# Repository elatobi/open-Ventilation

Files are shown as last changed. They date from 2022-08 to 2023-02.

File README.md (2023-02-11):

# Open-Ventilation



This is an Arduino sketch to PWM controll a 12V Fan, the PCB files for the PCB and the CAD-Data for my Printercabinet housing. 

The mainscreen shows the current temperature, material and the dutycicle of the fan.



By pressing the button of the rotaryencoder for 3s, the setup menu gets opend. Ther you can set the different materials.
For now there is PLA, PETG, FLEX, PC and IGLIDUR a material from Igus. 
Each material has its own min and max temp. Between thise temperatures the fan runns with a maped dutycicle, below the min temp the fan is not running.
Abov the max temp the fan runns with 100% dutycicle.



In the PCB folder are the files for getting the PCB according to the circuit diagram.





You can finde the CAD-Files for the Housing at my Printables Profile https://www.printables.com/de/model/162908-housing-for-cabinet-ventilation-control

# BOM

1 x Arduino Nano\
1 x 16x2 LCD with i2C backpack\
1 x DS18B2\
1 x Rotaryencoder with button\
1 x IRFZ44N MOSFET\
1 x 1N4007 Diode\
1 x 10 kΩ Resistor\
1 x 4,7 kΩ Resistor\
1 x 220 Ω Resistor\
1 x 12V Fan (2 or 3 Wire)\
1 x 12V powersuply

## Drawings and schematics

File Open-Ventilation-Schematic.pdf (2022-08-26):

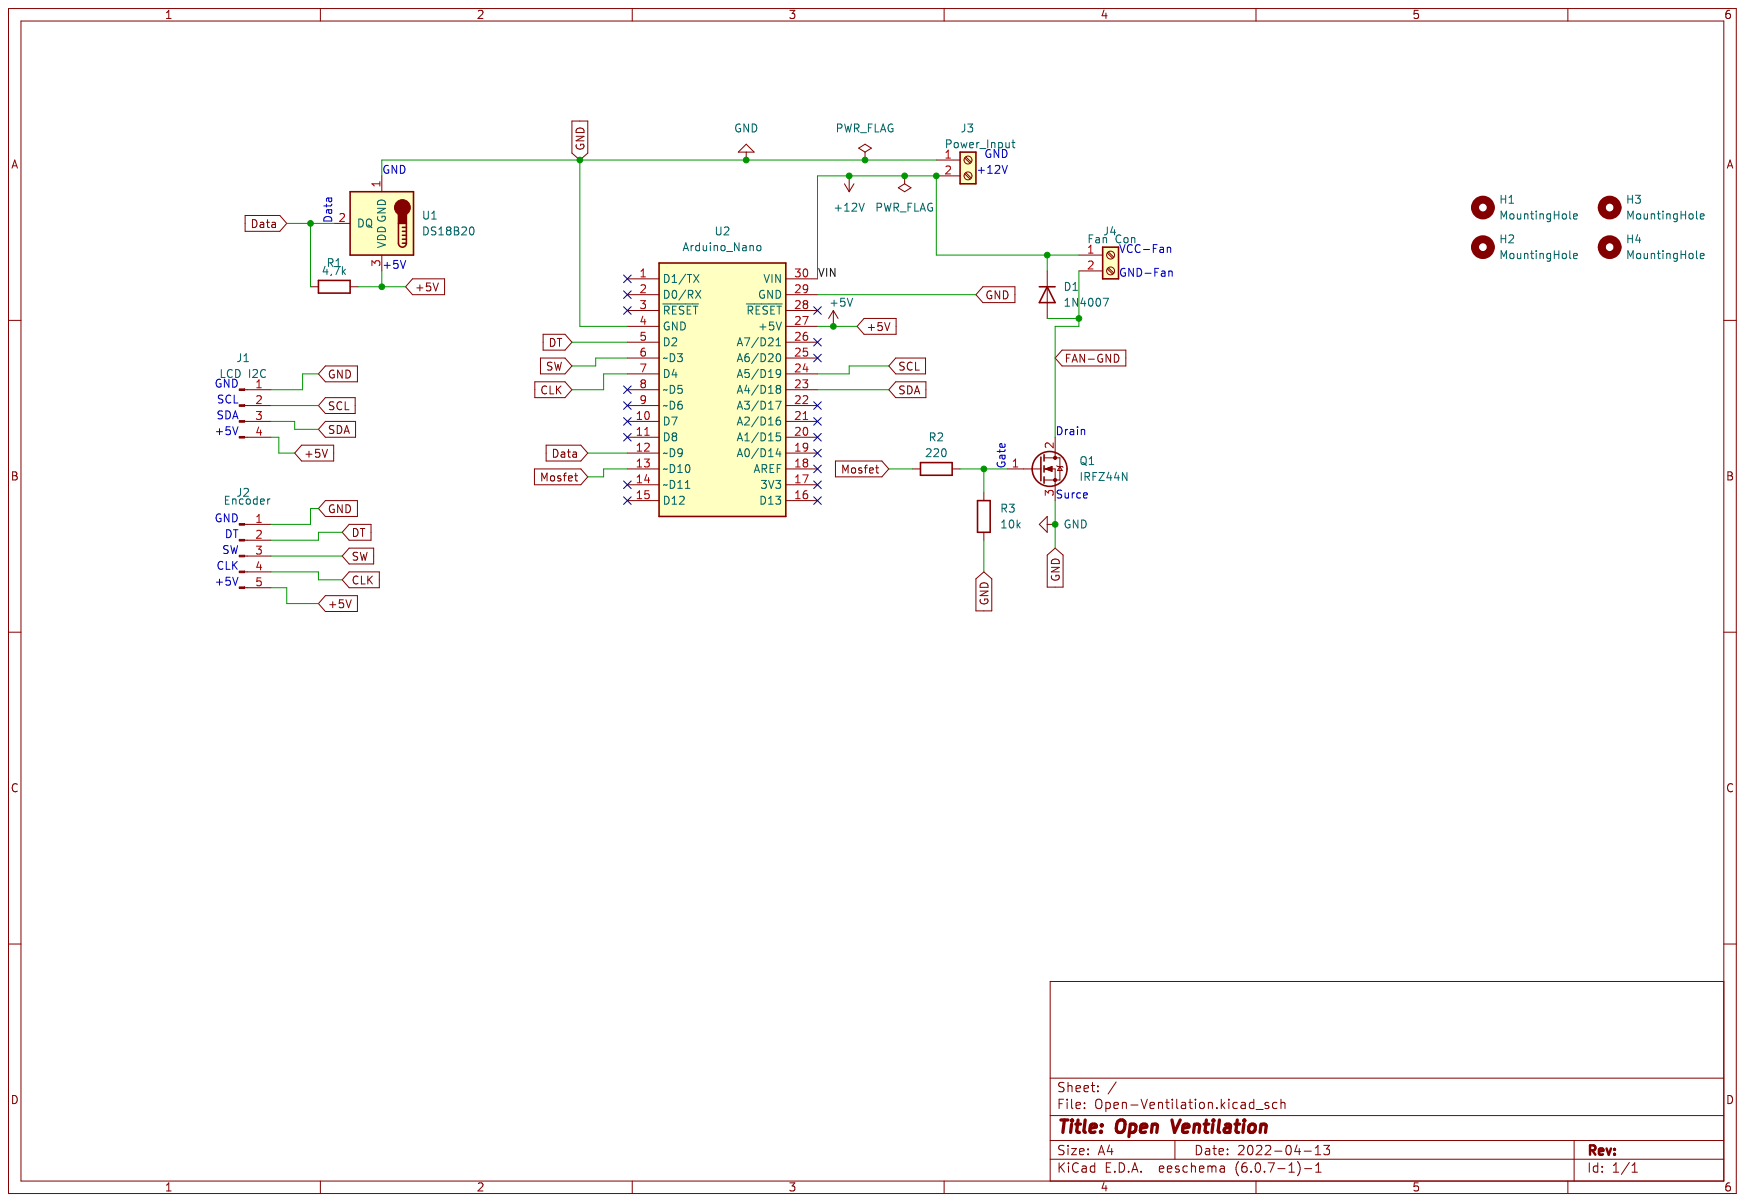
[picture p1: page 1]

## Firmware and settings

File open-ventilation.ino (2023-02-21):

#include <Arduino.h>
#include <LiquidCrystal_I2C.h>
#include <Wire.h>
#include <Adafruit_Sensor.h>
#include <DHT.h>
#include <DHT_U.h>
#include <OneWire.h>
#include <DallasTemperature.h>
#include <Encoder.h>
#include "OneButton.h"


LiquidCrystal_I2C lcd(0x27, 16,2);

#define ONE_WIRE_BUS 9  // Onewire Bus @ Pin 9

OneWire oneWire(ONE_WIRE_BUS);  //generating OneWire Bus 
DallasTemperature sensors(&oneWire); // Starting Temp Sensor
DeviceAddress Thermometer;    // creating Name of the themp sensor

Encoder myencod(2,4); // creating Encoder


//defining some global Variables and setting the start/standart value

long position = 0;
const int readTimer = 1000;
float readTime = 0;
bool newRead = false;

byte fanspeed = 0;
int fanpercent = 0;
const int fanmin = 20;
float fantime = 0;
const int timer = 2500;
bool fanboost = false;
bool prevFanSpeed = 0;

int maxtemp = 35;
int mintemp = 20;

const int PinSW = 3;    
byte prevKeyState = HIGH;
float keypresstime = 0;
int keytime = 3000;

int menuestate = 0;
int menueselect = 0;
bool menuflag = false;
int menudelay = 150;
bool menuset = false;
int menuinit = 0;

String mode = "PLA";
bool modeFlag = true;

float tempC;
int fan = 10;

//crating function for the botscreen 
void initdysplay(){
  lcd.clear();
  lcd.setCursor(1,0);
  lcd.print("Starte System!");
  for (int i = 0; i < 16; i++)
  {
   lcd.setCursor(i,1);
   lcd.print("*");
   delay(150);
  }

}

void display(){
  lcd.clear();
  lcd.setCursor(2,0);
  lcd.print("Temp:");
  lcd.setCursor(12,0);
  lcd.print((char)223);
  lcd.print("C");

  lcd.setCursor(0,1);
  lcd.print("M:");

  lcd.setCursor(7,1); 
  lcd.print("Fan:");

}

void displayValue(){
  for (int i = 7; i < 12 ; i++)
  {
    lcd.setCursor(i,0);
    lcd.print(" ");
  }
  
  lcd.setCursor(7,0);
  lcd.print(tempC);

  if (modeFlag == true)
  {
    for (int i = 2; i < 7; i++)
    {
      lcd.setCursor(i,1);
      lcd.print(" ");
    }
    
    lcd.setCursor(2,1);
    lcd.print(mode);
    modeFlag = false;

  }
  

  for (int i = 11; i < 16 ; i++)
  {
    lcd.setCursor(i,1);
    lcd.print(" ");
  }

  lcd.setCursor(11,1); 
  lcd.print(fanpercent);
  lcd.print("%");
}


// creaing function for the menu
void displayMenu(){

  while (menuflag)  // loop depending on the menuflag, is running while true 
  {
    
    if (menuset == true)
    {
      lcd.clear();
      lcd.home();
      lcd.print("*****MENUE******"); 
      delay(2000);
      menuset = false;
      digitalWrite(PinSW, HIGH);
      menuflag = HIGH;
    }
        
    position = myencod.read()/4;  // read the postion of the encoder
    menuestate=position;    
   
    if (position <= 0){   // checking if the encoder has value <0
      menuestate = 0;   // seting the menu variable to 0 for encoder postions <0
      myencod.write(0);    
    }
    else if (position > 4)
    {
      menuestate = 4;
      myencod.write(16);
    }
        
    switch (menuestate)   // switching between the different menuoptions
    {      

    case 0:
      lcd.clear();
      lcd.home();
      lcd.print(">PLA");
      lcd.setCursor(1,1);
      lcd.print("PETG");
      if (digitalRead(PinSW)== LOW)
      {
        menueselect = 1;
      } 

      break;

    case 1:
      lcd.clear();
      lcd.setCursor(1,0);
      lcd.print("PLA");
      lcd.setCursor(0,1);
      lcd.print(">PETG");
      if (digitalRead(PinSW)== LOW)
      {
        menueselect = 2;
      }      

      break;

    case 2:
      lcd.clear();
      lcd.setCursor(0,0);
      lcd.print(">FLEX");
      lcd.setCursor(1,1);
      lcd.print("PC");
      if (digitalRead(PinSW)== LOW)
      {
        menueselect = 3;
      }     

      break;

    case 3:
      lcd.clear();
      lcd.setCursor(1,0);
      lcd.print("FLEX");
      lcd.setCursor(0,1);
      lcd.print(">PC");
      if (digitalRead(PinSW)== LOW)
      {
        menueselect = 4;
      }      

      break;

    case 4:
      lcd.clear();
      lcd.setCursor(0,0);
      lcd.print(">IGLIDUR");
      
      if (digitalRead(PinSW)== LOW)
      {
        menueselect = 5;
      }      

      break;
    
    }

    delay(menudelay);


    Serial.print(menuflag);
    Serial.println(menueselect);

    switch (menueselect) // Settings depending on the selectet material and resetting some flags for the menue
    {
    case 1:
      mode = "PLA";
      mintemp = 20;
      maxtemp = 35;
      menuflag = false;
      menueselect = 0;
      keypresstime = 0;
      modeFlag = true;

      break;
    
    case 2:
      mode = "PETG";
      mintemp = 20;
      maxtemp = 40;
      menuflag = false;
      menueselect = 0;
      keypresstime = 0;
      modeFlag = true;

      break;

    case 3:
      mode = "FLEX";
      mintemp = 20;
      maxtemp = 45;
      menuflag = false;
      menueselect = 0;
      keypresstime = 0;
      modeFlag = true;
    
      break;

    case 4:
      mode = "PC";
      mintemp = 26;
      maxtemp = 55;
      menuflag = false;
      menueselect = 0;
      keypresstime = 0;
      modeFlag = true;

      break;

    case 5:
      mode = "IGLI";
      mintemp = 28;
      maxtemp = 50;
      menuflag = false;
      menueselect = 0;
      keypresstime = 0;
      modeFlag = true;

      break;

    default:
      break;      
    
    }
  
  }
  keypresstime = 0;
  display();            // display the standard screen 
  displayValue();       // display the curent Values 
  
}




void readSensor(){
  
  sensors.requestTemperatures();            //getting the temperatuer from the sensor 

  tempC = sensors.getTempC(Thermometer);

  if (tempC >= mintemp && tempC <= maxtemp)   // map the speed of the fan depending on the Temp range of the material
  {
    fanspeed = map(tempC, mintemp, maxtemp, 0, 255);
  
  }
  else if (tempC > maxtemp)     // set the max speed of the fan if the Temp is over the max temp
  {
    fanspeed = 255;
  }
  else 
  {
    fanspeed = 0;
  }

  fanpercent = map(fanspeed, 0, 255, 0,100);  //map the speed to the % dutycicle 
  

  if (fanpercent < fanmin)          // the fan is not realy running if the dutycicle is less then 20%
  {
    fanspeed = 0;
    fanpercent = 0; 
  }



  if (fanpercent > 0 && prevFanSpeed == 0) //set a Flg to boost the Fan for a save startup wenn the fan was not running bevore
  {
    fanboost = true;
  }

  if (fanpercent < fanmin)
  {
    prevFanSpeed = 0;
  }
  else
  {
    prevFanSpeed = 1;
  }

  
}


void setup() {

  Serial.begin(115200);

  pinMode(PinSW,INPUT_PULLUP);
 
  pinMode(fan, OUTPUT);
  
   
  sensors.begin();    
  sensors.getAddress(Thermometer, 0);

  lcd.init();
  lcd.backlight();
  initdysplay();
  display();

}

void loop() {

  if (digitalRead(PinSW) == HIGH)  // query if the rotaryencoder is pressed to start the menu 
 {
   prevKeyState = HIGH;
 }
 else
 {
   if (prevKeyState == HIGH)
   {
     keypresstime = millis();
     prevKeyState = LOW;
   }
   if ((millis()-keypresstime) >= keytime)
   {
     menuflag = true;
     menuset = true;
     menuinit = 1;
   }
 }

 switch (menuinit)
 {
 case 1:              //going to the setup menu
   displayMenu();
   menuinit = 0;
   break;
 
 default:

 if (fanboost == true )   //wehn the Fanboost flag was set, here the fan runs for 2,5s at full speed, to get it reliable runns
 {
   fantime = millis();
   fanboost = false;

   while (millis() - fantime <= timer)
    {
      analogWrite(fan, 255);
    }
 }


 analogWrite(fan, fanspeed);  // write the normal fanspeed to the pin 
 displayValue();              // display the current values
 readSensor();                // get new temp values from the sensor
  break;

 }
  

}
